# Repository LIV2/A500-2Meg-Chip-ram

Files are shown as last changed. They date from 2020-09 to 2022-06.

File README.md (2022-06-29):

# A500/2000 2MB Chip RAM Mod

This is an adapter board to retrofit a 2MB Agnus into an Amiga 500/2000 and also includes 2MB of chip ram

### A version that uses a PLCC plug instead of pinheaders is available [Here](https://github.com/LIV2/A500-2Meg-Chip-ram/tree/PLCC)

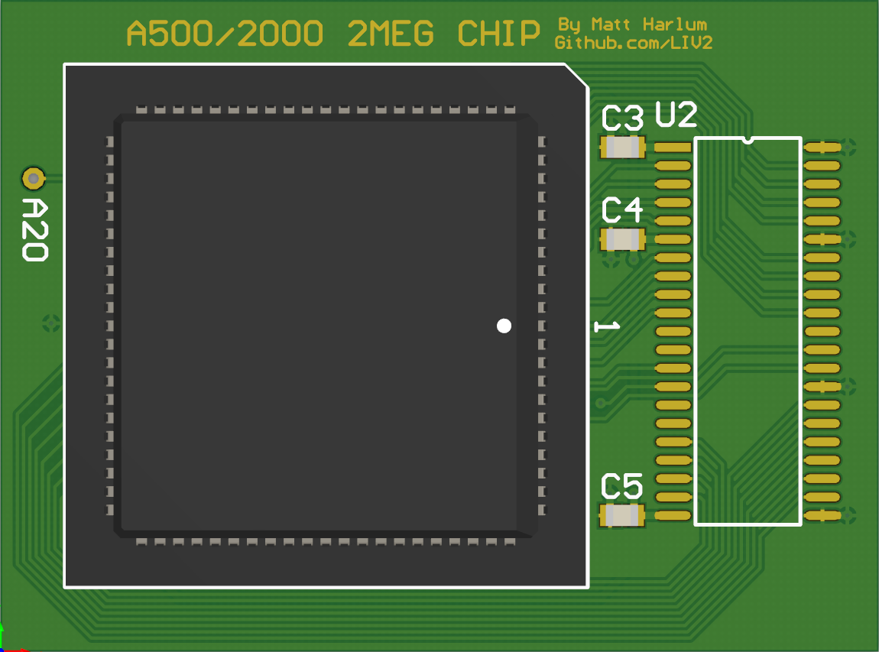
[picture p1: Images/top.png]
PCB Top

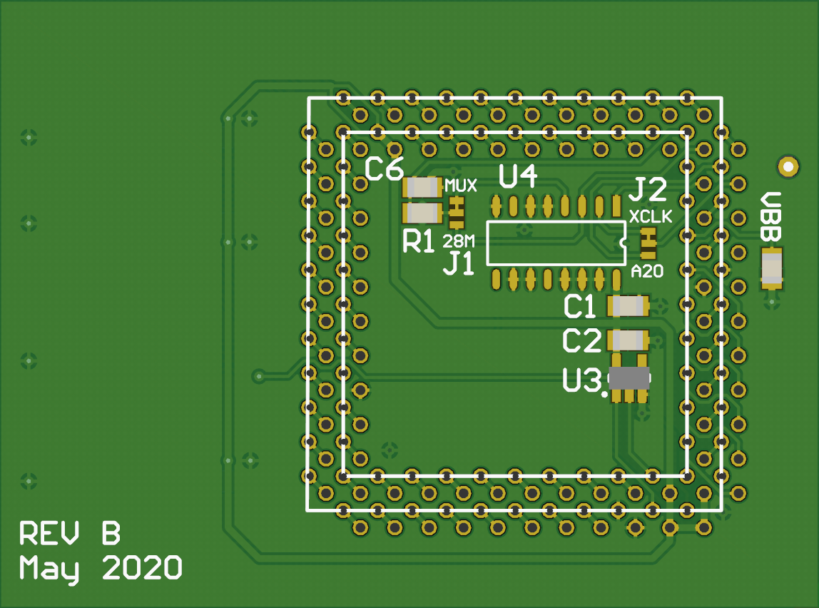
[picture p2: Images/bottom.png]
PCB Bottom


## Assembly Steps
1. Solder the DRAM, U4, U3
2. Solder the Capacitors & Resistor (Only fit VBB capacitor if your Agnus says VBB on the top!)
3. Solder the PLCC Socket making sure that the socket aligns exactly with the outline on the top of the PCB!
4. After soldering the socket, you may want to trim the joints down to the PCB to make soldering the pin headers easier. <br/>**Be careful when trimming the leads that you don't scratch the PCB solder mask!**
5. Prepare the pin headers by removing a pin from this corner of each as indicated here:<br/>
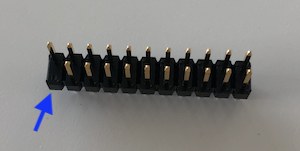
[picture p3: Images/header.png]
remove

6. Insert one of the pin headers just far enough for it to hold, making sure that it is level.<br/>
The side with the removed pin goes where indicated by the yellow arrow<br/>
I recommend doing them one by one in the order indicated:<br/>
If you will be soldering to the Amiga rather than using sockets, I would recommend soldering the long side of the pins to the adapter<br />
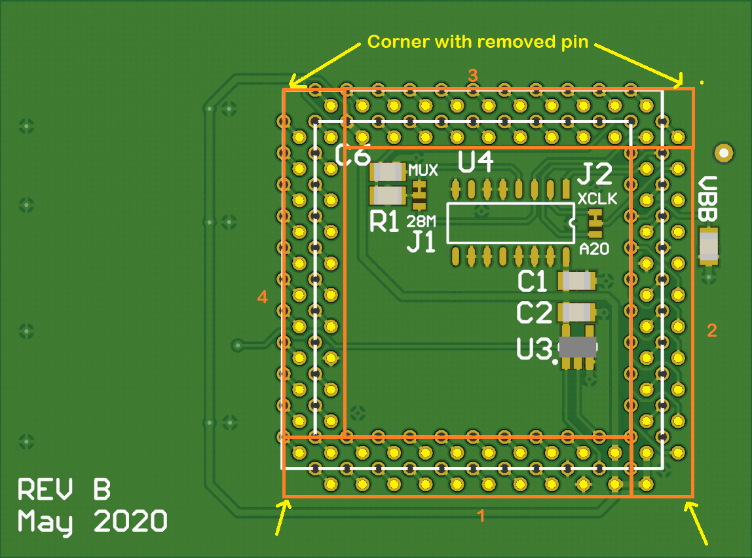
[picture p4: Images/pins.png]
locations

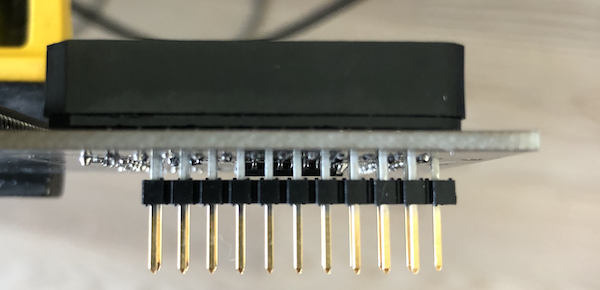
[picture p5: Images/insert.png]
insert


7. Solder in each pin, don't use too much solder!
8. Repeat for each pin header<br/>
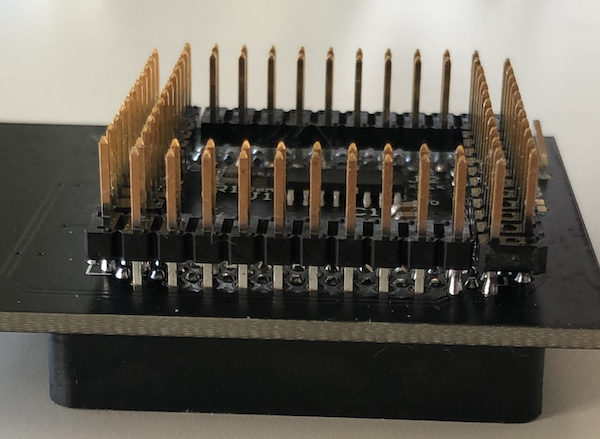
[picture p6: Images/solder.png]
solder

9. Solder a wire to A20 and connect the other end at one of the following locations:
   * Gary pin 36
   * CPU pin 48
   * JP5 Top left pad (A500 Rev 6)
10. Make sure that JP2 is set as shown:<br/>
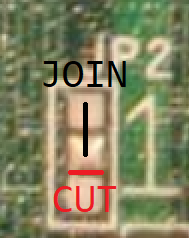
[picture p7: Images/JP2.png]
jp2

11. Carefully desolder & remove the Agnus socket
12. Remove the same corner pin from each pin socket and solder them in replacing the agnus socket
13. Insert the adapter
**To make sure it is installed the correct way, pay attention to the marking of "1" on the PCB and on the Amiga they must match**<br />
On a Rev 6A Amiga 500 this means that the ram will be on the right hand side, on a Rev 5 it will be pointing downwards instead.<br />
look from the sides to make sure the pins are going in to the headers<br />
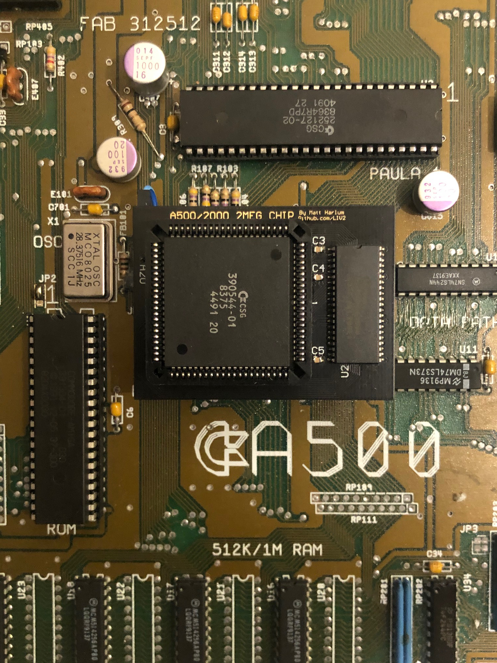
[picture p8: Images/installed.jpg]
installed


## A20 Connection
### A500
Solder a wire to A20 and connect the other end at one of the following locations:
   * Gary pin 36
   * CPU pin 48
   * JP5 Top left pad (A500 Rev 6)

### A2000
Solder a wire to A20 and connect the other end at one of the following locations:
   * Gary pin 36
   * CPU pin 48
   * Also available from a via next to the power connector as indicated here:  
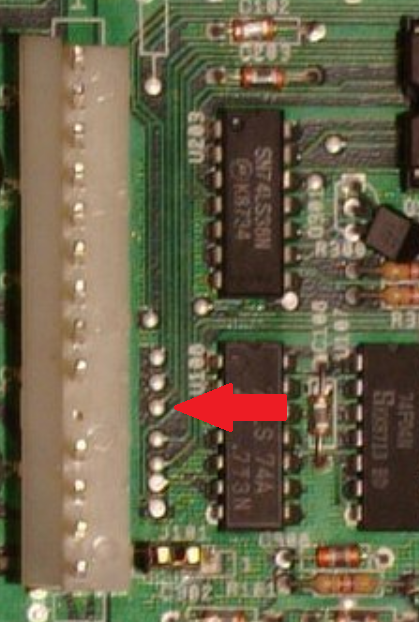
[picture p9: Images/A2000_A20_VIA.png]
a20_via
   

### A1000 Rejuvinator
A20 is available from Pin 15 of U28 on the Rejuvinator

## Jumper Settings
The default jumper settings do not need to be changed and will work on all systems. 

Rev 6A Amiga 500's have jumpers that can be used to provide the A20 signal on pin 35 instead of XCLK
This allows us to use this adapter without having to add the wire to A20 but note **this will mean you cannot use a genlock on this Amiga!**

In this case you must set J1 to 28M to bypass the XCLK/28M Mux then set J2 of the adapter to A20<br />
If you wish to do this then you will also need to change the jumper settings at J5 on your A500 motherboard<br />
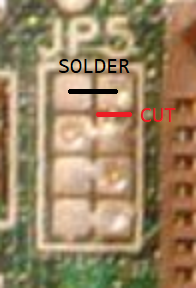
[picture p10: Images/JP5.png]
jp5


## Bill of materials
|Component|Location|QTY|Link|Notes|
|---|---|---|----|-----|
|Ceramic Capacitor, 0.1uF, 0805|C1-5,C7|6|[Mouser](https://www.mouser.com/ProductDetail/710-885012207098)||
|Ceramic Capacitor, 22pF, 0805|C6|1|[Mouser](https://www.mouser.com/ProductDetail/710-885012007053) ||
|Resistor, 150 Ohm, 0805|R1|1|[Mouser](https://www.mouser.se/ProductDetail/652-CR0805JW-151ELF)||
|74AHC1G08 Single 2-Input AND Gate, SOT-23-5|U3|1|[Mouser](https://www.mouser.com/ProductDetail/595-SN74AHC1G08DBVR)||
|74AHCT158 Quad 2-input Multiplexer, SOIC-16|U4|1|[Mouser](https://www.mouser.com/ProductDetail/595-SN74AHCT158D) |Optional, set J1 to "28M" to bypass|
|PLCC-84 Socket, Through-hole|U1|1|[Mouser](https://www.mouser.com/ProductDetail/437-5408808424008) ||
|5V, 1Mx16 EDO/FPM DRAM, SOJ-42<br>- K4F151611<br>- K4E151611<br>- GM71C18163C<br>- AS4C1M16E5|U2|1|eBay, Aliexpress etc||
|22-Pin, 2 Row Female header||4|[Mouser](https://www.mouser.se/ProductDetail/517-929975-01-11-RK)||
|22-Pin, 2 Row Male header||4|[Mouser](https://www.mouser.se/ProductDetail/649-77313-118-22LF)||

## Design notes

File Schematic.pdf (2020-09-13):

A1 60 | A2 61 | A3 62 | A4 63 | A5 64 | A6 65 | A7 66 | A8 67 | A9 68 | A10 69 | A11 70 | A12 71 | A13 72 | A14 73 | A15 74 | A16 75 | A17 76 | A18 77 | A19 59
A1 60 | A2 61 | A3 62 | A4 63 | A5 64 | A6 65 | A7 66 | A8 67 | A9 68 | A10 69 | A11 70 | A12 71 | A13 72 | A14 73 | A15 74 | A16 75 | A17 76 | A18 77 | A19 59

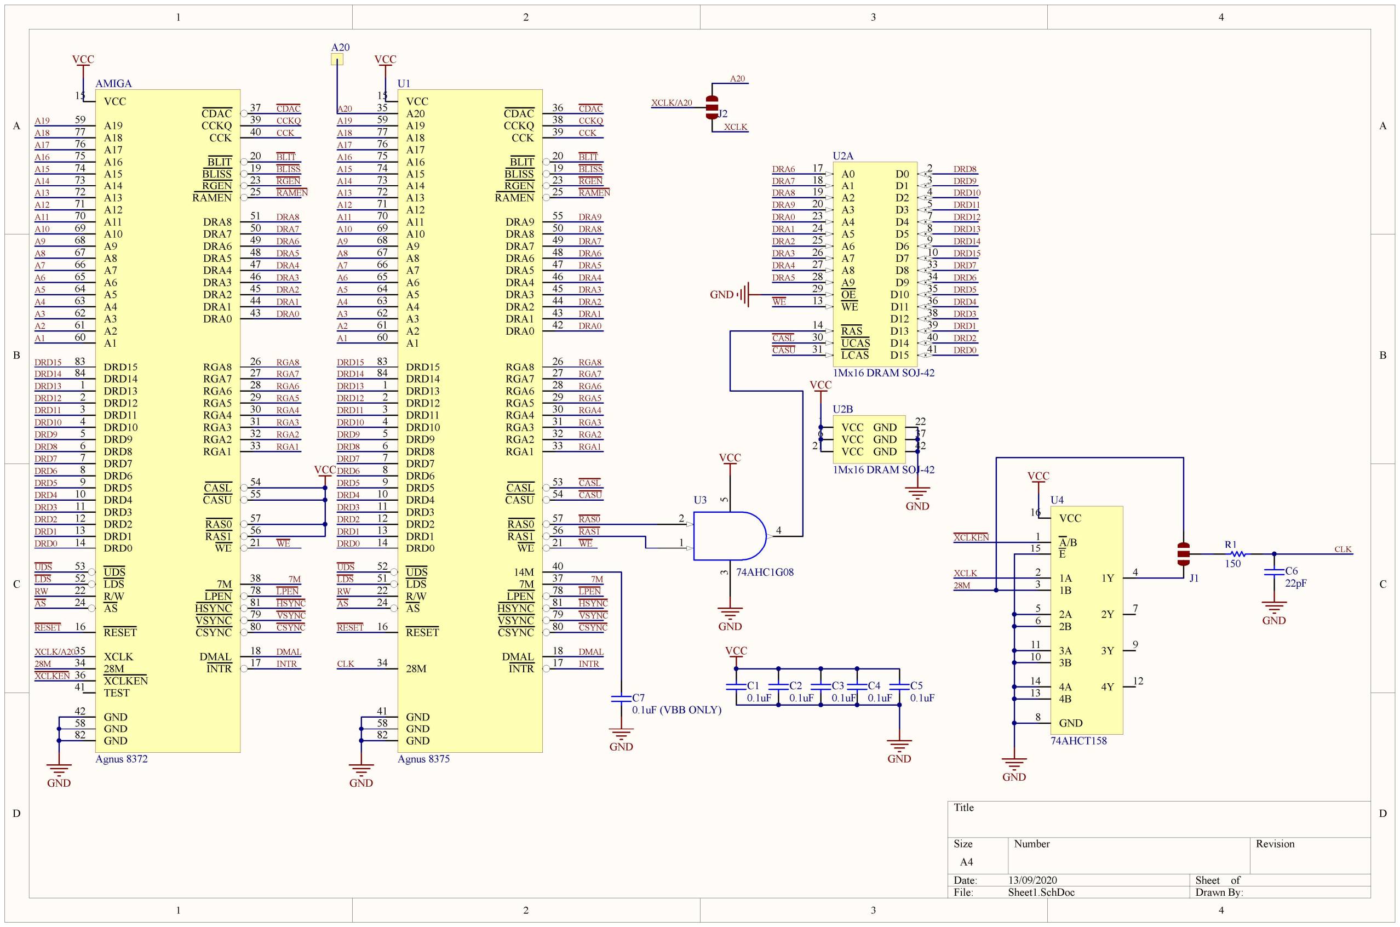
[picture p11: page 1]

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
Title

Size | Number | Revision
A4
Date: | 13/09/2020 | Sheet of
File: | Sheet1.SchDoc | Drawn By:

RGA1

RGA2

RGA3

RGA4

RGA5

RGA6

RGA7

RGA8

RGA1

RGA2

RGA3

RGA4

RGA5

RGA6

RGA7

RGA8

DRD0

DRD1

DRD2

DRD3

DRD4

DRD5

DRD6

DRD7

DRD8

DRD9

DRD10

DRD11

DRD12

DRD13

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
DRD0

DRD1

DRD2

DRD3

DRD4

DRD5

DRD6

DRD7

DRD8

DRD9

DRD10

DRD11

DRD12

DRD13

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
DRA0

DRA1

DRA2

DRA3

DRA4

DRA5

DRA6

DRA7

DRA8

DRA9

RAMEN

RGEN

BLISS

BLIT

CCK

CCKQ

CDAC

CASL
CASU

RAS0
RAS1
WE

7M
LPEN
HSYNC
VSYNC
CSYNC

DMAL
INTR

RAMEN

RGEN

BLISS

BLIT

CCK

CCKQ

CDAC

7M
LPEN
HSYNC
VSYNC
CSYNC

DMAL
INTR

GND

VCC | VCC

UDS
LDS
RW
AS

RESET

CLK

GND

UDS
LDS
RW
AS

RESET

WE

XCLK/A20
28M
XCLKEN

DRA0
DRA1
DRA2
DRA3
DRA4
DRA5

DRA6
DRA7
DRA8
DRA9

DRD0

DRD1
DRD2

DRD3

DRD4

DRD5

DRD6

DRD7

DRD8
DRD9
DRD10
DRD11
DRD12
DRD13

CASL
CASU

DRD14
DRD15

DRD13 1
DRD12 2
DRD11 3
DRD10 4
DRD9 5
DRD8 6
DRD7 7
DRD6 8
DRD5 9
DRD4 10
DRD3 11
DRD2 12
DRD1 13
DRD0 14

UDS 52

CASL 53

RESET 16

R/W 22
AS 24

A20 35

28M 34

CDAC 36

GND 41

RAMEN | 25 RGEN | 23 BLISS | 19 BLIT | 20
14M | 40
CCK | 39
7M | 37
RGA8 | 26
RGA7 | 27
RGA6 | 28
RGA5 | 29
RGA4 | 30
RGA3 | 31
RGA2 | 32
RGA1 | 33
DRA1 | 43 DRA2 | 44 DRA3 | 45 DRA4 | 46 DRA5 | 47 DRA6 | 48 DRA7 | 49 DRA8 | 50

LDS 51

CASU | 54
DRA9 | 55
RAS1 | 56
WE | 21
CCKQ | 38
LPEN | 78
HSYNC | 81
VSYNC | 79
CSYNC | 80
DMAL | 18
INTR | 17
RAS0 | 57
DRA0 | 42

GND 58
GND 82

VCC 15

DRD15 83
DRD14 84

U1

Agnus 8375

DRD14

DRD15
DRD14

DRD15

GND

WE

GND

VCC

GND

DRA0

DRA1

DRA2

DRA3

DRA4

DRA5

DRA6

DRA7

DRA8

VCC

VCC

GND

VCC

GND

XCLKEN

28M

XCLK | J1

CLK

A20

GND

J2

XCLK/A20

XCLK

A20

A20

D0 | 2
D1 | 3
D2 | 4
D3 | 5
D4 | 7
D5 | 8
D6 | 9
D7 | 10
D8 | 33
D9 | 34
D10 | 35
D11 | 36
D12 | 38
D13 | 39
D14 | 40
D15 | 41

A0 17
A1 18
A2 19
A3 20
A4 23
A5 24
A6 25
A7 26
A8 27
A9 28

WE 13

RAS 14

OE 29

LCAS 31 UCAS 30

U2A

1Mx16 DRAM SOJ-42

GND | 22
GND | 42 VCC 21 | VCC 6 | GND | 37 VCC 1

U2B

1Mx16 DRAM SOJ-42

C4
0.1uF

C5
0.1uF

C1
0.1uF

C2
0.1uF

C3
0.1uF

VCC

C7
0.1uF (VBB ONLY)

GND

R1
150 C6
22pF ³

2

1 5

4

U3

74AHC1G08

A/B 1

1A 2
1B 3

1Y 4

2A 5
2B 6

2Y 7

GND 8

3Y | 9
3B 10 | 3A 11
4Y | 12
4B 13 | 4A 14

E

15

VCC 16

U4

74AHCT158

DRD13 1
DRD12 2
DRD11 3
DRD10 4
DRD9 5
DRD8 6
DRD7 7
DRD6 8
DRD5 9
DRD4 10
DRD3 11
DRD2 12
DRD1 13
DRD0 14

LDS 52 UDS 53

RESET 16

R/W 22
AS 24

XCLK 35
28M 34
XCLKEN 36
TEST 41
RAMEN | 25 RGEN | 23 BLISS | 19 BLIT | 20
CCK | 40 CCKQ | 39 CDAC | 37
RGA8 | 26
RGA7 | 27
RGA6 | 28
RGA5 | 29
RGA4 | 30
RGA3 | 31
RGA2 | 32
RGA1 | 33
DRA0 | 43 DRA1 | 44 DRA2 | 45 DRA3 | 46 DRA4 | 47 DRA5 | 48 DRA6 | 49 DRA7 | 50 DRA8 | 51
CASL | 54
CASU | 55
RAS1 | 56
WE | 21
7M | 38
LPEN | 78
HSYNC | 81
VSYNC | 79
CSYNC | 80
DMAL | 18
INTR | 17
RAS0 | 57

GND 42
GND 58
GND 82

VCC 15

DRD14 84 DRD15 83

AMIGA

Agnus 8372

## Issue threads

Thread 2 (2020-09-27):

A500 Plus version possible?

nsxsn, 2020-09-27:
Would it be possible to have a version of this board that works in A500+ (in fact A500++) motherboard?

This would be extremely useful when repairing an A500 Plus with the Rob Taylor's A500++ board.
I found your "Diet-Agnus-A500-plus" via his Tindie DIY projects page, but it is "only" 1MB and I have of course the 8375 Agnus.

I would like to keep my A500 Plus motherboard untouched and having RAM in a board like this seems very nice indeed.

I love soldering stuff, but I can't design these thing and I don't think I have the years left anymore to learn :)

LIV2, 2020-09-29:
Hi @nsxsn

Unfortunately I don't have the time to work on this life gets in the way!

There are other options though, like Kai Robinson's DRAM board here: https://github.com/kr239/A500-DRAM-Board

nsxsn, 2020-09-29:
Thank you for your reply!

I hope one day you will have time (then again I have no idea how big a task it is) :)

Actually I have built that Kai Robinsson's DRAM board, but my A500++ repair build is not far enough to test it yet.

I just thought your Agnus implementation is very nice and compact.

I'll close this issue :)

Closed 2020-09-29.

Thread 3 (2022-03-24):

Black screen

bit-image, 2022-03-24:
I installed this board into an A2000 Rev 6.2 and now I only see a black screen, even with DiagRom. I am using this with a 390544-01 in PAL mode. Any assistance would be appreciated. A20 is connected to pin48 on the CPU.

LinuxJedi, 2022-03-25:
This basically means the board can't talk to Agnus properly. You don't need to hook up the A20 line to test, it will just show 1MB RAM instead of 2MB.

First obvious thing is to check the orientation is correct.

Check the soldering for U4 as that handles the clock (you can also check the 7M clock output to the CPU with a scope). Then check the soldering for Agnus pins / socket for bad joins / shorts.

Also, check the power light on the Amiga comes on (indication of a 5v / GND short if it doesn't).

LIV2, 2022-03-25:
Pretty much what @LinuxJedi said :) It would be helpful to see some photos of the bottom of the adapter clearly showing the orientation of U4

bit-image, 2022-03-25:
Thanks for the assistance, please see photos enclosed. Orientation of U4 appears correct, however the righting on the chip is hard to make out.

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

manmax1, 2022-03-25:
Hello ! I am the one that built the meg-chip.
First, this one has been tested and running fine, so I don't know what is happening. Maybe issue with bottom pins, as you know we can apply little amount of solder, and maybe during shipping something broke a solder joint.....I really don't know.  I am scared by my joint with this good zoom :) but I I really checked continuity 2 or 3 times on each components to avoid problems. If we can't solve this I will build a new one for bit-image.  Maybe we can try to bypass u4 by setting the jumper to 28m ? It removes a potential chip fail ?

bit-image, 2022-03-26:
I set the jumper to 28M, no change. I do not have a scope to test 7M

LIV2, 2022-03-26:
It may be possible to test if it's a motherboard soldering issue without having to desolder the headers by pushing some [machined pin sockets](https://www.amazon.com/ZYAMY-2-54mm-Female-Straight-Connector/dp/B0778TFL39) into the sockets on the motherboard then you plug a PLCC socket in top of that (making sure to correctly orientate the socket) and finally plug the original Agnus into that and test.

This may not work if the female headers you used are too tall, but it does work for the ones I used & listed in the readme

bit-image, 2022-03-26:
I've already tested the connectivity of the soldered motherboard headers with my meter.

LIV2, 2022-03-27:
It could be a bad solder joint on the adapter then perhaps it is worth reflowing the pins, socket and the bottom ics.
Even if the ram had a bad joint the system should partially boot diagrom

LIV2, 2022-07-12:
Closing because there have been no updates, reopen if needed

Closed 2022-07-12.

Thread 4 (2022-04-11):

Orientation in a Amiga 500 Rev5

mamejay, 2022-04-11:
Hi Team,
Could be a silly question.  All screenshots I see the 2meg adapter mounted horizontally.
With my motherboard, pin 1 face down and not to the right of the socket..  So would that mean I mount the adapter vertically?
Just want to make sure as pictures from https://bigbookofamigahardware.com/bboah/media/download_photos/a500mb_rev5_3.jpg
show that pin one is down but the agnus in this screenshot is facing to the right.  My Amiga has the Angus mounted with pin 1 down.
Hope this makes sense.

LIV2, 2022-04-11:
Hi,

Yes on rev 3 & 5 A500's pin one faces the front of the Amiga, so on these revisions it needs to be mounted with pin 1 pointing towards the front

Closed 2022-04-29.

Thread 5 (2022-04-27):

PAL/NTSC AGNUS interoperability?

DoctorDan1986, 2022-04-27:
Can someone confirm this for me?  I'm reading that a PAL 318069-xx AGNUS can work on an NTSC Amiga?

https://eab.abime.net/showthread.php?t=92402

I'd love to be able to upgrade my NTSC A2000 with this board.

LIV2, 2022-04-28:
This is correct however using a PAL Agnus in an NTSC Amiga will result in the machine outputting in a PAL mode (with bad timings because the Amiga has an oscillator for NTSC Timings)
The screen mode can be changed in workbench back to an NTSC mode but this will not have any effect for games etc.

Running in PAL mode with an NTSC Amiga may work with some monitors / scandoublers and not others but I have not tested this myself beyond running a PAL Amiga in NTSC mode with a 1084S which worked with no issues

DoctorDan1986, 2022-04-28:
> This is correct however using a PAL Agnus in an NTSC Amiga will result in the machine outputting in a PAL mode (with bad timings because the Amiga has an oscillator for NTSC Timings) The screen mode can be changed in workbench back to an NTSC mode but this will not have any effect for games etc.
>
> Running in PAL mode with an NTSC Amiga may work with some monitors / scandoublers and not others but I have not tested this myself beyond running a PAL Amiga in NTSC mode with a 1084S which worked with no issues

As I'm running this into a Framemeister, toys shouldn't be an issue.  Thanks for the confirmation!

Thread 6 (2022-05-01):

Black Screen - PLCC version

mamejay, 2022-05-01:
Hi Team,
I have made up a few boards using the PLCC method.  I now get a black screen and diagrom fails to start.
I am using Diagrom VIA a Pistorm which normally gives me serial output on screen but it just hangs.
I am using a Rev5 board which has pin one of the Agnus pointing down.
Only thing I have different on my boards is that I have not install the 74AHCT158 multiplexer and just connected 28M jumper.
Could this have something to do with it?  I have now ordered some HCT158 chips and hope this may sort out the issue.
Any thoughts are welcome.
Thanks

LIV2, 2022-05-01:
Hi,

I don't think the lack of a multiplexer is causing your problem. Can you please share a photo of one of these adapters top and bottom?

A few questions:
* Which version of Agnus are you using? What is the part number printed on it
* Did you connect A20?
* Did you use the correct part for U3? it needs to be a 74AHC1G08

I would check if Agnus is working + generating the clock signals by probing the clock signals at pins 26,27,28 of Gary for example.

One thing I found when assembling these was that it is very easy to get shorts on the plug side, solder can creep up the legs and cause short circuits so I'd recommend checking closely between the pins
There should only be continuity between the neighboring pins indicated in the red box here:

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

mamejay, 2022-05-02:
Here are the pictures.  I have tested with A20 connected and not connected as LinuxJedi mentioned that it will still work for testing.
I have the same results with 3 boards and there are no shorts between the socket pins.  I have included the label of the label of the part for 74AHC1G08 I am using from LCSC.
I will check to see if clock is being generated on Gary when I finish work for the day.

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

LIV2, 2022-05-02:
Maybe try removing C6, perhaps it is causing issues on the clock signal for some reason.

Other than that it is a passive adapter so there isn't much to go wrong besides shorts between the pins or bad contact with the socket.
Even if there's an issue with the ram chip or the single gate IC you should get some diagrom serial output on Pistorm.

mamejay, 2022-05-02:
Success!! I started checking continuity of the pins on the PLCC socket and found a couple of my boards had bridges.  Could not see them at all so you are correct they are underneath.  As I made 5 boards just in case I tested another that had no bridges and it fired up.
One question.  What is the advantage of using the 74AHCT158 as opposed to not?  Is it better?
I have them on order either way.

PS: Disregard my Frankenstein machine.  I have a HDMI switcher mounted inside my case for a single HDMI output for Pistorm and RGB2HDMI

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

LIV2, 2022-05-02:
Great stuff :)

The '158 is there to allow use with Genlocks which supply their own 28MHz clock - Earlier models of Agnus had this feature built in but with the 2MB one Commodore removed that feature so it had to be done with external logic.

Not many people are going to need that functionality these days so there's no huge need to fit the 158

Closed 2022-05-03.

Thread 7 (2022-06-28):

Amiga 1000 Rejuvenator

Ed82, 2022-06-28:
Any idea where to connect A20 when using on a Rejuvenator Board in an Amiga 1000, other than CPU Pin 48, to use 2MB ChipMem? Works fine without A20 connected and 1MB ChipMem or with A20 connected with CPU Pin 48 and 2MB ChipMem.

Thx in advance

LIV2, 2022-06-29:
Hi @Ed82,

I took a look at the Rejuvinator schematics and it looks like you can get A20 from pin 15 of U28 on the rejuvinator itself

Ed82, 2022-06-29:
Hello @LIV2,

thx for the answer. I tested it and it works. You can update the Readme.md if you want to.

Closed 2022-06-30.

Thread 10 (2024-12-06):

Inquiry for a custom Amiga project

2mg, 2024-12-06:
Hello,

I saw your Amiga oriented GitHub repositories, and saw your [A500-2Meg-Chip-ram](https://github.com/LIV2/A500-2Meg-Chip-ram).

I'm asking if you'd be willing to consider making a dual Agnus 2xPLCC socket board with a switcher.

As I like to do as little fiddling as possible with old hardware, having an Agnus switcher (between OCS and ECS, specifically 1MB only) would mean a tremendous lot for me, as I'd plug that in once, forget about it and reduce any further strenuous activity on that Agnus socket and Agnus itself.

There is even a PLCC84 plug from 2 different sources for fitting this custom board into the Agnus socket, and since I want only the 1MB 8372(A) ECS Agnus (there are 2 specific 8375 1MB that are pin compatible too) there is no need for any converters.

If you're interested, I can make a little donation, or buy it straight from you preassembled, the BOM will possibly be really small AFAIK, I can source my own Agnuses.

You could further experiment with this approach to switch between OCS and ECS 2MB versions, but I just need the OCS and ECS 1MB approach.

Please let me know if you plan on doing this!

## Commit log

2020-09-13 Add assembly steps, correct BOM
2020-09-13 Schematic: Update part number for U4
2020-09-18 Move Drill files to Gerber directory
    [PCB1.GBL, PCB1.GBO, PCB1.GBP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]
2026-05-14 Added Kicad version
2026-05-14 Update README.md for Kicad version
2026-05-14 Add PDF schematics for Kicad version
